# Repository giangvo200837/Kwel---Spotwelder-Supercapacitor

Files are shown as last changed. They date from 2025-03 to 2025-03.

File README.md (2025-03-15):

# PIC Microcontroller Spotwelder SuperCAP
 
# Supercapacitor Spot Welder – DIY & Fully Adjustable

This spot welder is a small project designed for use with two or three pairs of Nippon Chemi-Con 1400F 2.5V capacitors connected in series. The circuit features a dual-pulse control system with adjustable timing and setting memory, ensuring precise and reliable welds.
# Key Features:
- Using PIC18 Microcontroller.
- Integrated LM2596 CC 2A Charger.
- Management VCap and Balancing Circuit with customizable discharge resistors and mosfet DPAK package.
- Input Voltage Range: DC 10V-15V (max).
- OLED Display (128x64) for monitoring and adjustments.
- Adjustable Pulse from 1ms to 30ms and Pulse 2 upto 50ms.
- Using 10 MOSFETs AUIRF8409, IRL40SC228 or any D2PAK-7Pin.
- Using Mosfet Driver MIC4424 non-inverting with 3A/Port/5MOS total 6A for all Mosfet, reduce rise time and fall time for reduce power loss and dissipation, with 10 IRL40SC228, total time charge is ~400nS.
- Using max 2.5V per Cap or 5V series.
# Two Operation Mode:
- Auto Mode (duration by +0.5s per set).
- Manual Mode (controlled via foot pedal or switch).

   Everything is done by hand (DIY) without having to spend any processing steps, easy to do at home.
# Youtube Overview

IMAGE ALT TEXT HERE (https://www.youtube.com/watch?v=iMLx_PU4esA)
   
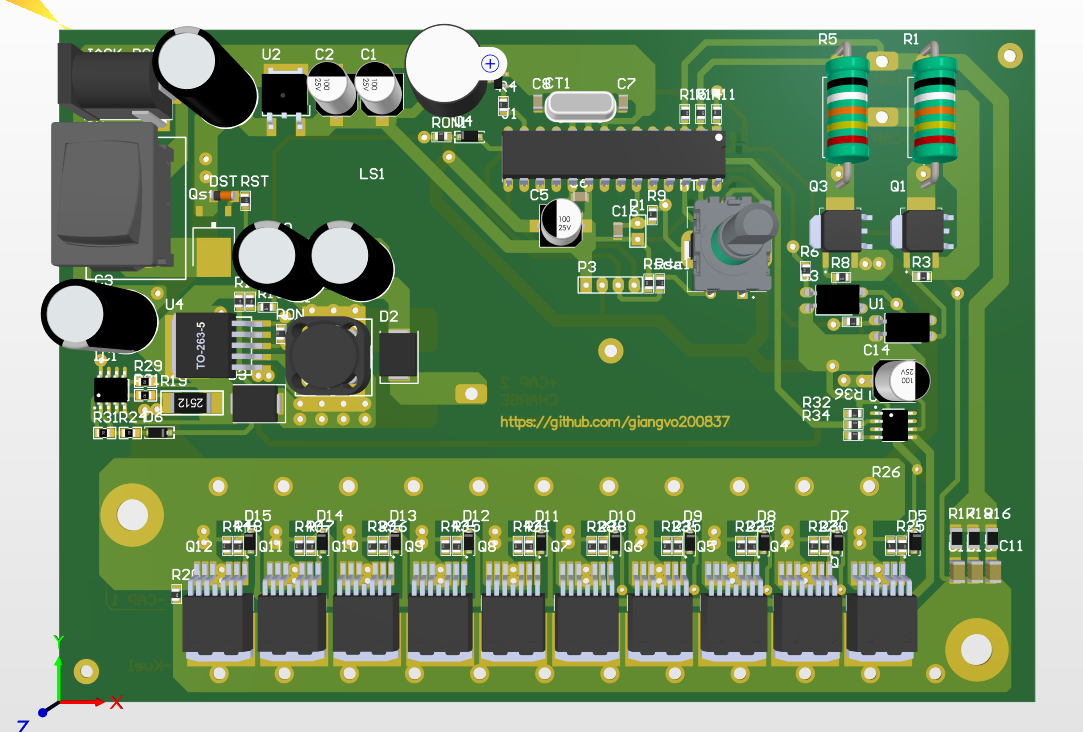
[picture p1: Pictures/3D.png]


I didn't add vias at the main power line and moved the part name on the top overlay because that's not necessary when diy PCB.

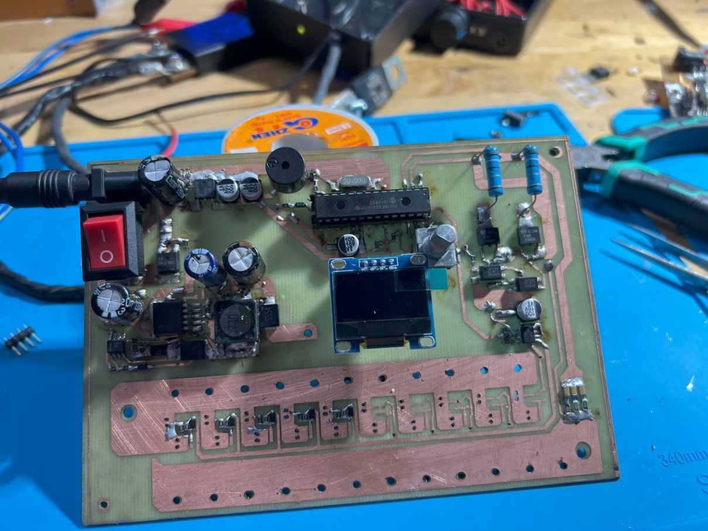
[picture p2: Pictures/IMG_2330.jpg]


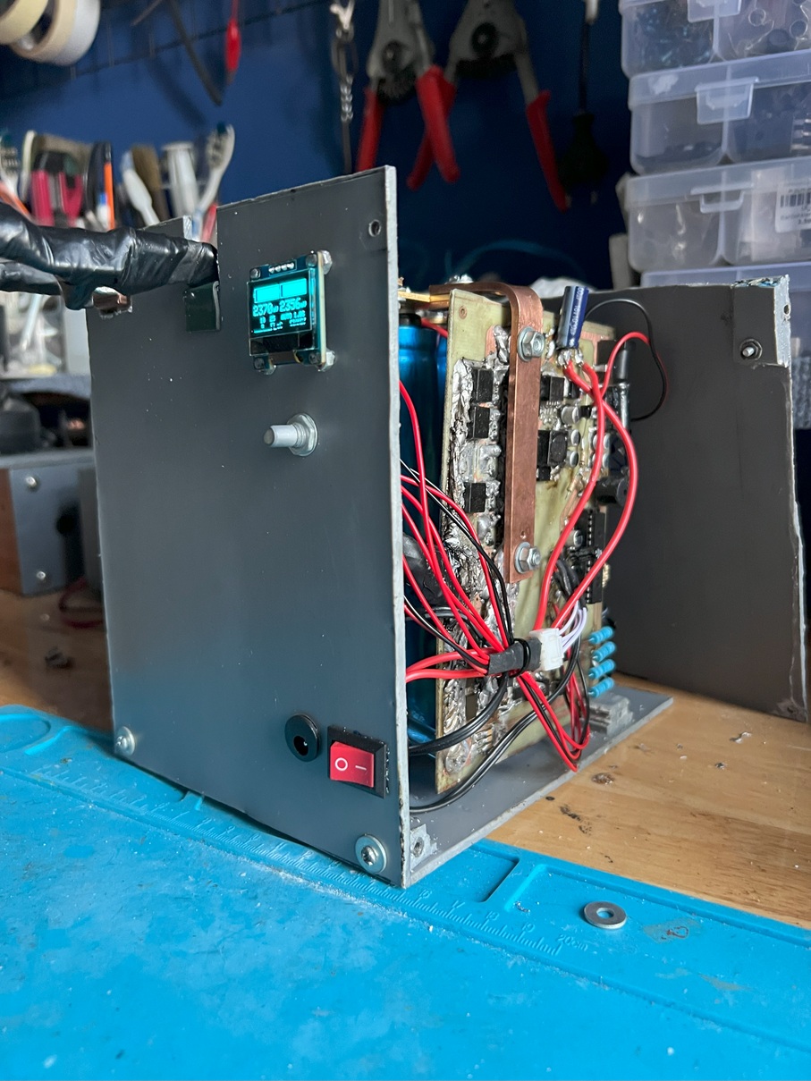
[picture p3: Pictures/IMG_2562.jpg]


# Connection Diagram

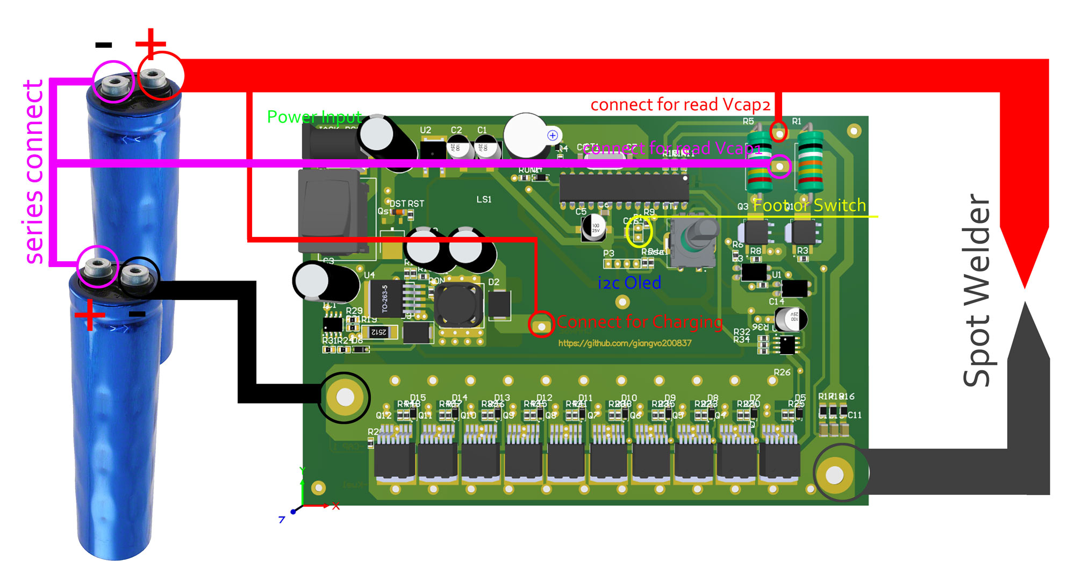
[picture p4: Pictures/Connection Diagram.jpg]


# Special Thanks
Simple Circuit SSD1306 Libraly custom for CCS C Compiler.

https://simple-circuit.com/ssd1306-oled-ccs-c-library/

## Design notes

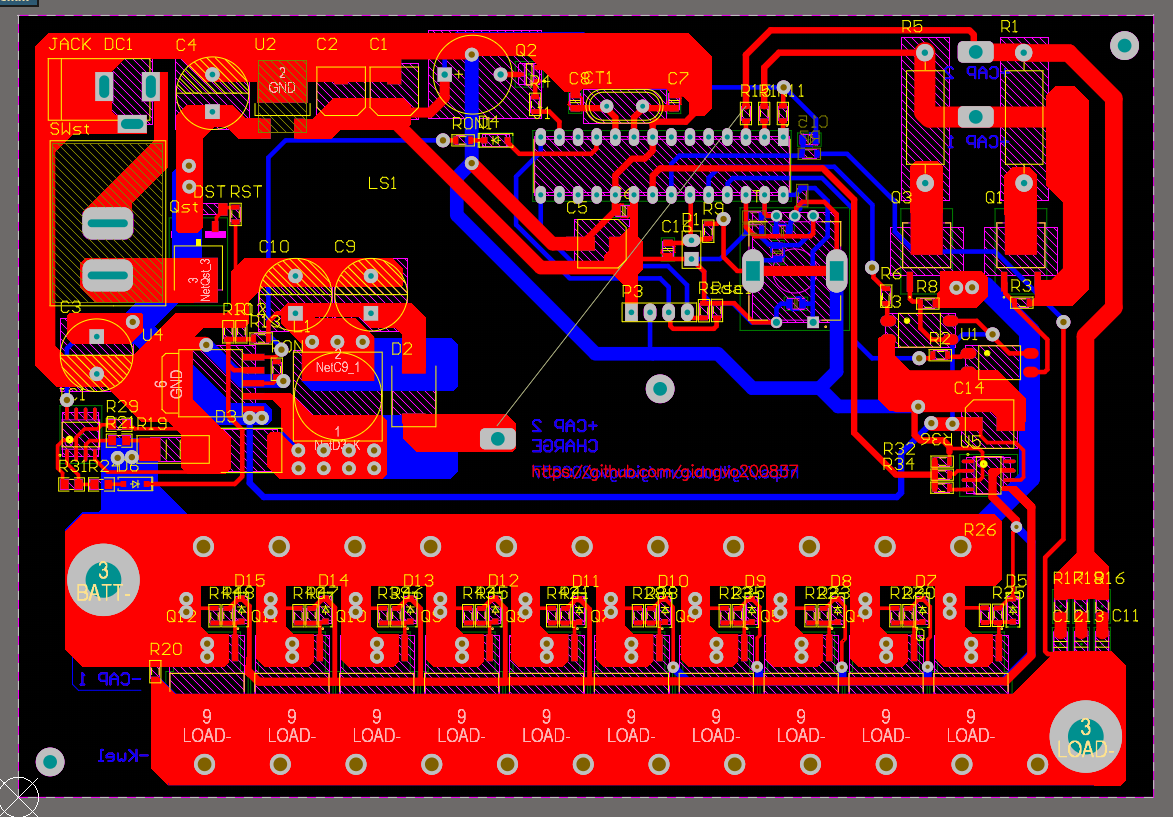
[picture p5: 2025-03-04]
Pictures/Layout.png

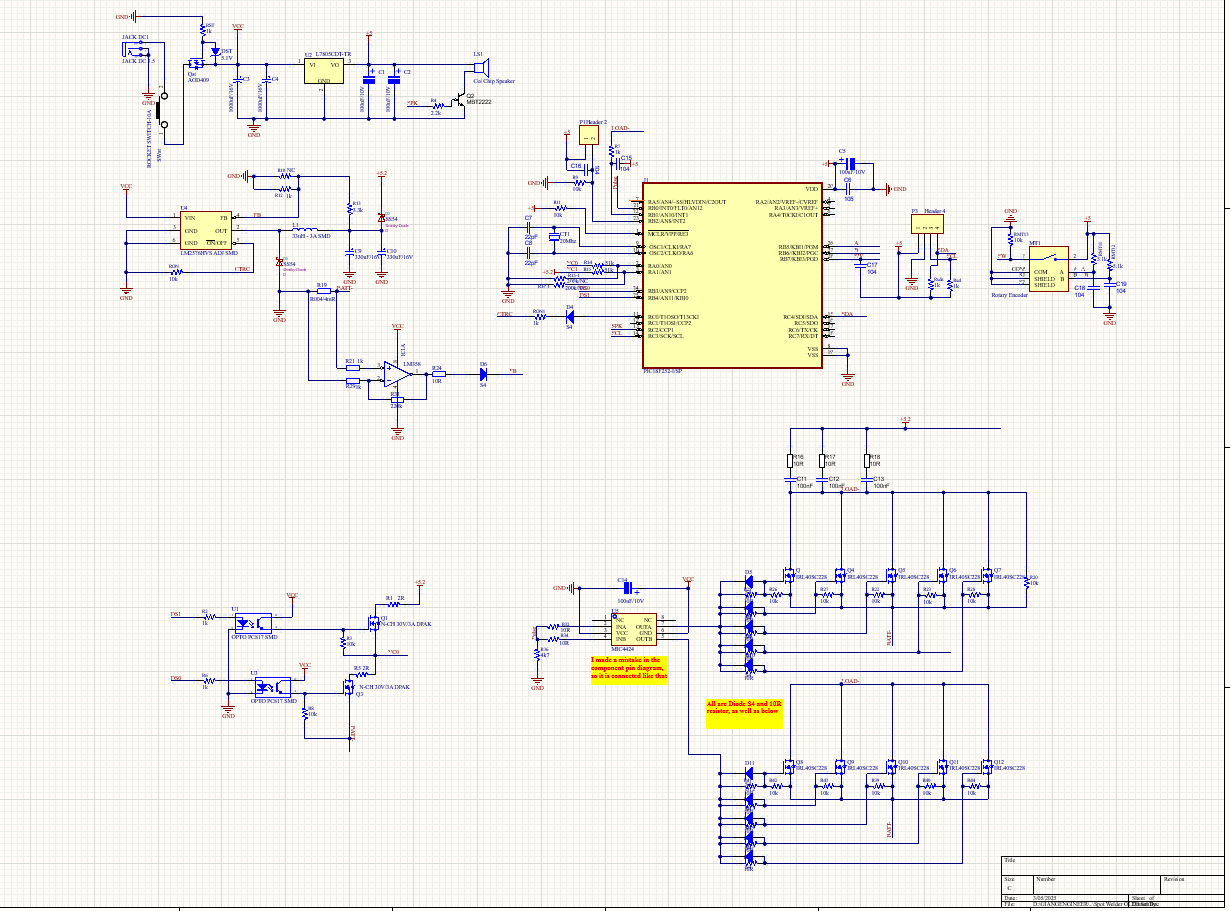
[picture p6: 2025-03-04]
Pictures/SCH.png

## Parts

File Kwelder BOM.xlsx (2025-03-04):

Comment | Description | Designator | Footprint | LibRef | Quantity
100uF/10V | Dán | C1, C2, C5, C14 | tu nhom 6.3 (d) | Tu Nhom 100uF 16V | 4
1000uF/16V | Cắm | C3, C4 | tu hoa 10mm | Tu Hoa 2200uF 16V 10x20 | 2
0805 | Capacitor SMD Cer 1.8nF 10% 50V X7R 0805 | C6, C7, C8, C15, C16, C17, C18, C19 | CAPC2012X135N | CAP C_0805 | 8
330uF/16V | Cắm | C9, C10 | tu hoa 10mm | Tu Hoa 2200uF 16V 10x20 | 2
1206 | Capacitor SMD Cer 220nF 10% 16V X7R 1206 | C11, C12, C13 | CAPC3216X180N | CAP C_1206 | 3
20Mhz | Crystal For all Crystal 2pin. | CT1 | CRYSTAL | CRYSTAL | 1
SS54 | SS54, [NoValue] | D2, D3 | DO-214AB_SMC | Schottky-Diode | 2
S4 | Dán | D4, D5, D6, D7, D8, D9, D10, D11, D12, D13, D14, D15 | DIODE SOD-123 | Diode S4 | 12
5.1V | Dán | DST | DIODE ZENNER SMD SOD80 | Diode Zener 5.1V | 1
LM358 | Low-Power Dual Operational Amplifier | IC1 | SOp 8 | LM358 | 1
PIC18F252-I/SP | PIC PICÂ® 18F Microcontroller IC 8-Bit 40MHz 32KB (16K x 16) FLASH 28-SPDIP | J1 | DIP787W46P254L3467H508Q28 | PIC18F252-I/SP | 1
JACK DC 5.5 | JACK DC 5.5 | JACK DC1 | JACK DC 5.5 | JACK DC 5.5 | 1
33uH - 3A SMD | Dán | L1 | Cuon Cam 12x12x10 | CUON CAM 100uH SMD | 1
Coi Chip Speaker | Còi chip | LS1 | Coi Chip Speacker | Coi Chip Speaker | 1
Rotary Encoder | Incremental Encoder, 12 Mm, Contact Rating 10 Ma - 5 Vdc | MT1 | XDCR_PEC11R-4215F-S0024 | PEC11R-4215F-S0024 | 1
Header 2 | Header, 2-Pin | P1 | HDR1X2 | Header 2 | 1
Header 4 | Header, 4-Pin | P3 | HDR1X4 | Header 4 | 1
N-CH 30V/3A DPAK | N-Channel 100 V 42A (Tc) 140W (Tc) Surface Mount D-Pak | Q1, Q3 | TO229P990X239-4N | IRFR3710ZTRPBF | 2
MBT2222 | Transistor SMD NPN 40V 600mA 250mW SOT23-3 | Q2 | SOT23-3 | NPN_MMBT2222A | 1
IRL40SC228 | OptiMOSâ„¢ 5 100V power MOSFET in TO-Leadless (TOLL) package with 60% space reduction for telecom and low voltage drives applications | Q, Q4, Q5, Q6, Q7, Q8, Q9, Q10, Q11, Q12 | DPAK127P1524X483-8N | IPT020N10N5 | 10
AOD409 | P-Channel 60V 26A (Tc) 2.5W (Ta), 60W (Tc) Surface Mount TO-252, (D-Pak) | Qst | TO252 | AOD409 | 1
2R | Res | R1, R5 | R2W | Res | 2
1k | Res | R2, R6, R7, R12, RON1, Rscl, Rsda, RST | SM-RES-0805 | Res SMD | 8
10k | Res | R3, R8, R9, R11, R20, R22, R23, R26, R27, R28, R39, R40, R42, R43, R44, RMT13, RON | SM-RES-0805 | Res SMD | 17
2.2k | Res | R4 | SM-RES-0805 | Res SMD | 1
NC | Res | R10 | SM-RES-0805 | Res SMD | 1
3.3k | Res | R13 | SM-RES-0805 | Res SMD | 1
200k/NC | Res | R14-1, R15-1 | SM-RES-0805 | Res SMD | 2
51k | Res | R14, R15 | SM-RES-0805 | Res SMD | 2
Thick Film | Resistor SMD chip 0.0 Ohm 0.25W 1206 | R16, R17, R18 | RESC3216N_ZERO | RES_1206 | 3
R004/4mR | Dán | R19 | tro smd 2512 | Tro 2512 5% 0.1R | 1
1k | Dán | R21, R29 | tro smd 0805 | Tro 0805 1% 1k | 2
10R | Dán | R24 | tro smd 0805 | Tro 0805 1% 1k | 1
10R | Res | R25, R30, R32, R33, R34, R35, R38, R41, R45, R46, R47, R48 | SM-RES-0805 | Res SMD | 12
220k | Dán | R31 | tro smd 0805 | Tro 0805 1% 33k | 1
4k7 | Res | R36 | SM-RES-0805 | Res SMD | 1
5.1k | Res | RMT11, RMT12 | SM-RES-0805 | Res SMD | 2
ROCKET SWITCH-10A | Rocker Switch SPDT 10A (AC) 125V Panel Mount, Snap-In | SWst | SW_2ARS_TH | SW1_10A-SRB23A2BBBNN-TH | 1
OPTO PC817 SMD | Single Opto | U1, U3 | SOP4 | OPTO PC817 SMD | 2
L7805CDT-TR | Linear Voltage Regulator IC 1 Output 1.5A DPAK | U2 | DPAK_118_446_112X59_SMD | REG_35V_5V-1.5A-7.5W-DPAK | 1
LM2576HVS ADJ SMD | Dán | U4 | TO263-5 | LM2576HVS ADJ SMD | 1
MIC4424 |  | U5 | SOp 8 | MIC4424 | 1

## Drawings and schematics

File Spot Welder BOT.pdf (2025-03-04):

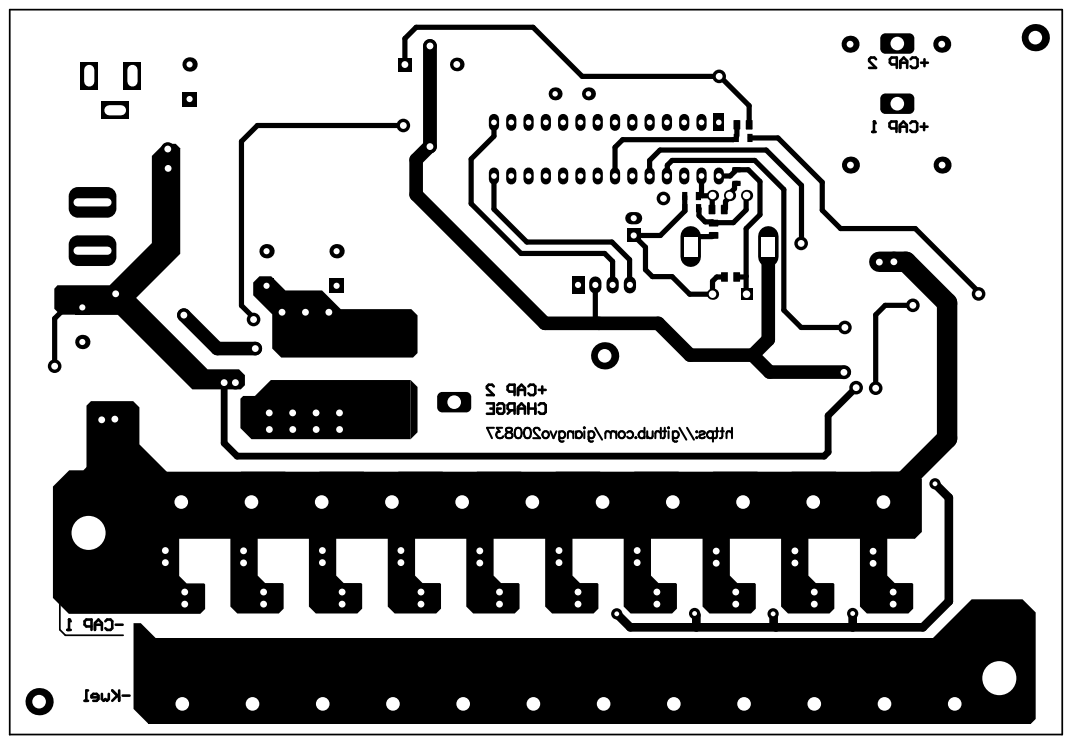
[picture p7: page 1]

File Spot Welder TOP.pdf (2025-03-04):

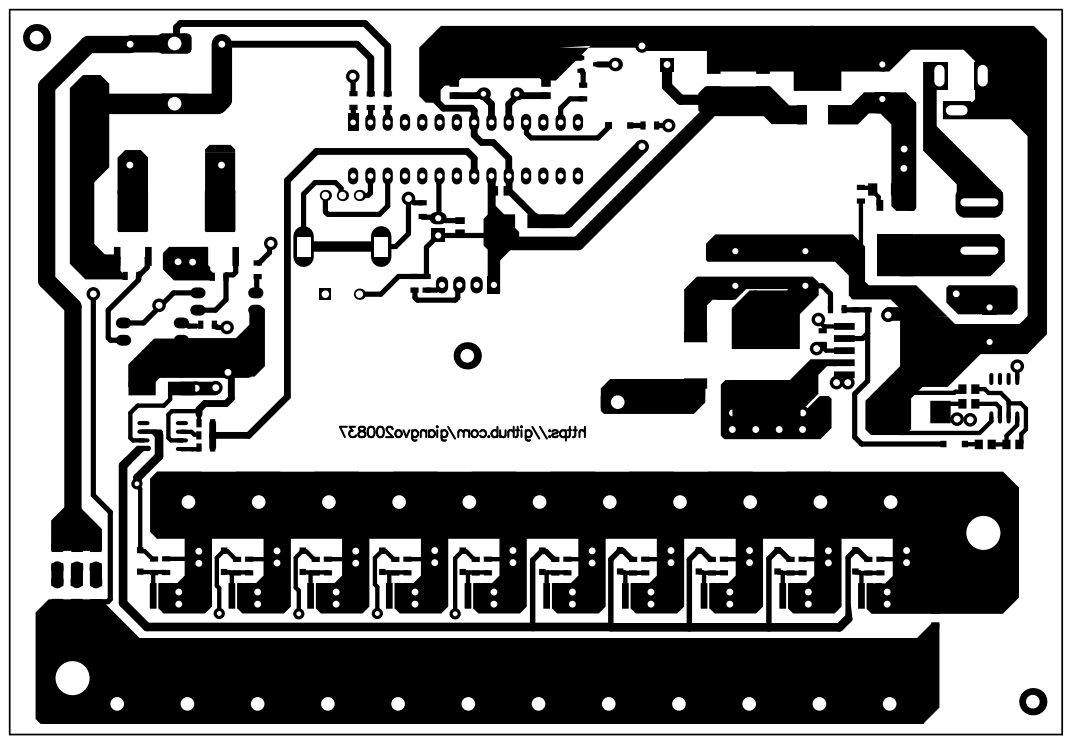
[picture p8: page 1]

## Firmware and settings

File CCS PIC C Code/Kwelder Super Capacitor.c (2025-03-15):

//#define SSD1306_RST    PIN_C0

#include <18F252.h>
#device ADC=10
#fuses HS, NOLVP, NOBROWNOUT, PUT, NOWDT, NOPROTECT
#use delay(clock=20MHz)
#use I2C(MASTER, I2C1, FAST = 400000, STREAM = SSD1306)
#define Charg PIN_C0
#define Pulse PIN_B0
#define button PIN_B7
#define sw_welder PIN_B2
#define welder_read PIN_B1
#define SPK PIN_C2
#define DS0 PIN_B3
#define DS1 PIN_B4
#define ENC_A PIN_B5  // Chân A cua encoder
#define ENC_B PIN_B6  // Chân B cua encoder
#define AN0_TO_AN1   0b0100
#include <SSD1306.c>      // include SSD1306 driver source code
#include <GFX_Library.c>  // include graphics library source code
#DEFINE LUUTRUT1 5
#DEFINE LUUTRUT2 10
#DEFINE LUUTRUC1 15
#DEFINE LUUTRUD1 20
// define random max number
#define RAND_MAX  (display_width - 1)
// include std library source code (required by rand() function)
#include <stdlib.h>
//!void testdrawrect(void) {
//!  for (int16_t i=0; i<display_height/2; i+=2) {
//!    display_drawRect(i, i, display_width-2*i, display_height-2*i, WHITE);
//!    display();
//!    delay_ms(1);
//!  }
//!}
int1 start = 0, dem_1 = 0,chedo = 0;
unsigned int8 chrgt = 0, chon = 0, dem = 0, dem_sw = 0, set_delay = 2, i = 0, a = 0;
//unsigned int percent0=0,bef0=64,percent1=0,bef1=0;
//unsigned int16 vt=0;
unsigned int16 Vcell[2];
unsigned int8 checkblc = 240, time1 = 1, time2 = 2;
unsigned int8 percent[2] = {0,0};
unsigned int8 before[2] = {128,64};
unsigned int16 dem2 = 65500, vcellr = 0;
int1 lastState = 0;
int1 currentState;
float Vtt = 0, seconds;
void drawrect(void)
{
   
   display_drawRect(7, 1, 58, 20,WHITE);
   display_drawRect(5, 8, 3, 5,WHITE);
   display_drawRect(70, 1, 58, 20,WHITE);
   display_drawRect(68, 8, 3, 5,WHITE);  
}

void balancing()
{

      if(Vcell[0] > 2499) {chrgt = 1;}
      if(chrgt == 1)      
         {
            output_high(Charg);
            output_high(DS0);
            output_low(DS1);
           // delay_ms(500); 
            
            if(Vcell[0] < Vcell[1])
            {
            output_low(Charg);
            output_low(DS0);
           // output_low(DS1); 
           chrgt = 0;
            }
          }
      if((Vcell[1] > 2499) && (chrgt == 0 )) {chrgt = 2;}
      if(chrgt == 2)
      {
         output_high(Charg);
         output_high(DS1);
         output_low(DS0);
         delay_ms(500); 
         chrgt = 2;
         if(Vcell[1] < Vcell[0])
         {
         output_low(Charg);
         output_low(DS0);
         output_low(DS1); 
         chrgt = 0;
         }
       }
       checkblc = 0;
   //}

    
}


int8 read_rotary(int8 counter)
{
        currentState = input(ENC_A);
        if (currentState != lastState) { // Kiem tra thay doi trang thái
            if (currentState == 0) { // Kiem tra huong quay
                if (input(ENC_B) == 0) {
                    counter++; 
                } else if(chon != 3) {
                    counter--; if(counter <= 1) {counter = 1;}
                }
            }
           if(dem2 >= 5000)
           {
            if(chon == 1) 
            {             
            if(counter >= 30) counter = 30;
            display_FillRect(17,45,12,8,black);
            display();
            display_setCursor(17, 45);
            printf(display_print,"%02u",counter);           
            display();
            //delay_ms(1);
            }
            
            if(chon == 2) 
            {
            
            if(counter >= 50) counter = 50;
            display_FillRect(42,45,12,8,black); 
            display();
            display_setCursor(42, 45);
            printf(display_print,"%02u",counter);
            display();
            //delay_ms(1);
            }
            
            if(chon == 3)
            {
            
            if(counter > 1) counter = 0;
            display_FillRect(58,45,66,8,black);
            display();
            display_setCursor(70, 45);
            if(counter == 1)
            {           
            display_print("AUTO");                      
            }
            else display_print("MANUAL"); 
            display();
            }
            
            if(chon == 4)
            {
            if(counter >= 6) counter = 6;
            display_FillRect(100,45,24,8,black); 
            display();
            display_setCursor(100, 45);
            seconds = counter;
            printf(display_print,"%1.1fS",seconds*0.5);
            display();
            }
            dem2 = 0;
           }
        }       
        lastState = currentState;
        return counter;
}

void read_analog(int adc_r)
   {    
   set_adc_channel(adc_r); 
   delay_ms(1);
   vcellr = 0;
   for (int z = 0; z<20; z++)
   {  
   vcellr = vcellr + read_adc();
   delay_us(100);
   }
   vcellr /= 20;
   Vcell[adc_r] = (float)(vcellr  * 5.0) / 1.023;  
   if(adc_r == 1) Vtt = Vcell[adc_r];
  // Vcell[adc_r] = 1450; // test voltage
   //return;
   }
   
void percentages(int16 volt)
 {
 if(volt>=2499) volt = 2499;
 percent[a] = (-0.022*(float)volt) + (128/(a+1)-1);
 if(percent[a] < before[a])  
 { 
    
   for(i = 128/(a+1); i > percent[a]; i--)
   {
   display_drawLine(i,3,i,18,WHITE); 
  if(start == 0) {display();} //first fill when start
   }  
 }
 
  if(percent[a] > before[a])  
 {  
   for(i = before[a]; i < percent[a]; i++)
   {
   display_drawLine(i,2,i,19,BLACK);  
  // display();
   }
 }
 before[a]=percent[a];
 //volt1=100;
 }

   
void draw_monitor(void)
{   
   display_FillRect(0,26,127,64,black);
   display_setTextColor(WHITE);
   display_setTextSize(1);   
   display_setCursor(50, 32);
   display_print("mV         mV");
   display_setCursor(17, 45);
   printf(display_print,"%02u",time1);
   display_setCursor(42, 45);
   printf(display_print,"%02u",time2);
   display_setCursor(59, 56);
   display_print("mS"); 
   display_setCursor(70, 45);
   if(chedo == 0)  display_print("MANUAL");
   else {
   display_print("AUTO");
   seconds = set_delay;
   display_setCursor(100, 45);
   printf(display_print,"%1.1fS",seconds*0.5);
   }
   display_setCursor(76, 55);
   printf(display_print,"Vp:%1.2fV",Vtt/1000); 
     //draw pulses    
   display_drawLine(1,63,20,63,WHITE);
   display_drawLine(20,63,20,55,WHITE);
   display_drawLine(20,55,23,55,WHITE);
   display_drawLine(23,55,23,63,WHITE);
   display_drawLine(23,63,43,63,WHITE);
   display_drawLine(43,63,43,55,WHITE);
   display_drawLine(43,55,50,55,WHITE);
   display_drawLine(50,63,50,55,WHITE);  
   display_drawLine(50,63,55,63,WHITE); 
   
   for(a = 0;a<2;a++)
      {  
         output_low(DS0);
         output_low(DS1);         
         read_analog(a); 
         if(chrgt == 1) output_high(DS0);        
         if(chrgt == 2) output_high(DS1); 
         Vcell[1] -= Vcell[0];         

         percentages(Vcell[a]);
         
         display_setTextSize(2);

         if(a == 1) display_setCursor(1, 26);
         if(a == 0) display_setCursor(68, 26); 
         printf(display_print,"%04lu",Vcell[a]);
         
//!         if((Vcell[0] == 0) && (Vcell[1] == 0)) 
//!         {
//!         
//!         display_FillRect(1,26,127,42,black);
//!         display_setCursor(19, 26);
//!         display_print("---  ---");
//!         }         
      }
      display();
      if((Vcell[0] > 2550) || (Vcell[1] > 2550))
      {
      Vcell[0] = Vcell[1] = 0; //drawrect();
      }     
      start = 1;     

}
void spotwelder_setup(void)
{        
         
         if(input(button)){
           while(input(button)){}//restart_wdt();delay_ms(200);}
           chon+=1;dem_1=1;
           if(chedo == 0) {if(chon > 3) chon = 5;}
           output_high(SPK);delay_ms(100);
           output_low(SPK);          
           if(chon <= 4)
           {
           display_FillRect(5,45,12,8,black); 
           display_FillRect(30,45,12,8,black); 
           display_FillRect(58,45,12,8,black);
           if(chedo == 1) {display_setCursor(100, 45);printf(display_print,"%1.1fS",seconds*0.5);}
           display();
           delay_ms(300);//restart_wdt();
           }          
           
           if (chon > 4) 
           {
           if(time1 >= 30) time1 = 30;
           if(time2 >= 50) time2 = 50;           
           write_eeprom(LUUTRUT1,time1);
           write_eeprom(LUUTRUT2,time2);
           write_eeprom(LUUTRUC1,chedo);
           write_eeprom(LUUTRUD1,set_delay);
           display_FillRect(0,26,127,64,WHITE);
           display_setTextColor(BLACK);
           display_setTextSize(2); 
           display_setCursor(40, 40);
           display_print("SAVED");
           display();delay_ms(1000);//restart_wdt();
           output_low(Charg);
           chon = 0; dem = 0; dem2 = 65500; break;  
          // reset_cpu();
           //break;//break;
            //break;
           }
         }
    if(chon == 1) { 
      time1 = read_rotary(time1);
    //  display_setTextSize(1);
    if(dem_1 == 1)
    {
      display_setCursor(5, 45);
      display_print(">>"); 
      display();
      dem_1 = 0;
    }
//!      display_setCursor(5, 45);
//!      display_print("  "); 
//!      display();
     // delay_ms(300);
    }
    if(chon == 2) {   
      time2 = read_rotary(time2); 
      //display_setTextSize(1); 
      if(dem_1 == 1)
    {
      display_setCursor(30, 45);
      display_print(">>"); 
      display();  
      dem_1 = 0;
    }
//!      display_setCursor(30, 45);
//!      display_print("  "); 
//!      display();
      //delay_ms(300);
    }
    if(chon == 3) { 
     // read_rotary();   
     chedo = read_rotary(chedo); 
      //display_setTextSize(1); 
      if(dem_1 == 1)
      {
      display_setCursor(58, 45);
      display_print(">>"); 
      display();
      dem_1 = 0;
      }
    }
    if(chon == 4) { 
     // read_rotary();   
     set_delay = read_rotary(set_delay); 
      //display_setTextSize(1); 
      if(dem_1 == 1)
      {
      display_setCursor(93, 45);
      display_print(">"); 
      display();
      dem_1 = 0;
      }
//!      display_setCursor(68, 45);
//!      display_print("  "); 
//!      display();
     // delay_ms(300);
    }
   // restart_wdt();
    dem2+=1;//if(dem2 > 5000) dem2 = 5000;
    //delay_us(10);
}

void spotwelder_start(int8 pulse1, pulse2)
   {  
      //setup_wdt(WDT_ON);
      //pulse_interval = pules1; if(pulse_interval >= 10) pulse_interval = 10;
      output_high(SPK);
      output_high(Pulse);delay_ms(pulse1);
      if(pulse1 > 10) pulse1 = 10;         //interval  
      output_low(Pulse);delay_ms(pulse1); //interval
      //restart_wdt(); 
      output_high(Pulse);delay_ms(pulse2);
      output_low(Pulse);delay_ms(10);
      //restart_wdt(); 
      output_low(SPK); //delay_ms(100);
//!      for(int z = 0; z < 5; z++)
//!      {
//!      delay_ms(100); 
//!      restart_wdt(); 
//!      }
      output_low(Pulse); //for sure
     // break;
     // restart_wdt(); 
     // setup_wdt(WDT_OFF);
   }


void main(void)
{
  // by default, we'll generate the high voltage from the 3.3v line internally! (neat!)
  // initialize with the I2C addr 0x7A (for the 128x64)
  // SSD1306 OLED display I2C address may be 0x7A or 0x78
 
  SET_TRIS_A(0B00000011);
  SET_TRIS_B(0b11100110);
  SET_TRIS_C(0b11000);
  output_low(Pulse);
  output_low(Charg);
  output_low(SPK);
  output_low(DS0);
  output_low(DS1);
  lastState = input(ENC_A);
//!  output_low(Pulseex);
//!  for(int h = 0; h<5; h++)
//!  {
//!  output_high(Pulseex);delay_ms(1000);
//!  output_low(Pulseex);delay_ms(1000);
//!  }
  setup_adc(ADC_CLOCK_DIV_8); 
  SETUP_ADC_PORTS(AN0_TO_AN1);
 // setup_wdt(WDT_2304MS);
  // setup_wdt(WDT_OFF);
 // restart_wdt();
  //setup_wdt(WDT_288MS);
 // SSD1306_begin(SSD1306_SWITCHCAPVCC, 0x7A); // test code
  SSD1306_begin(SSD1306_SWITCHCAPVCC, 0x78); // load code
  
  time1 = read_eeprom(LUUTRUT1); if(time1 >  99) {time1 = 3; write_eeprom(LUUTRUT1,time1);}
  time2 = read_eeprom(LUUTRUT2); if(time2 >  99) {time2 = 5;write_eeprom(LUUTRUT2,time2);} 
  chedo = read_eeprom(LUUTRUC1); if(chedo >  1) {chedo = 0;write_eeprom(LUUTRUC1,chedo);}
  set_delay = read_eeprom(LUUTRUD1); if(set_delay >  6) {set_delay = 2;write_eeprom(LUUTRUD1,set_delay);}
   //display_clear();
//!   display();
//!   delay_ms(1000);
   ssd1306_command(SSD1306_SETCONTRAST);
   ssd1306_command(0xB9);
//!   display_FillRect(0,0,127,63,white);
//!   display_setTextColor(Black);
//!   display_setTextSize(3); 
//!   display_setCursor(2, 25);
//!   display_print("GIANG J");
   //display_FillRect(0,0,127,63,black);
   display();
  // restart_wdt();
   output_high(SPK); delay_ms(500);
   output_low(SPK);
   delay_ms(2000);
   //restart_wdt();
   display_clear();
   drawrect();
  //output_high(Charg);
  // init done
  while(true)
  {  

  if(dem2 >= 65500)
  {
    draw_monitor();
    //display();
    checkblc+=1; if (checkblc > 10) {checkblc = 10;}
     dem2=0;
  }
  

  
if((Vcell[0] > 1000) && (Vcell[1] > 1000) && (time1 <= 30) && (time2 <= 50))
{
 if(dem == 0)
   { 
   //do spotwelder
   if(chedo == 0)
   {
      if(input(sw_welder)){ 
      while(true){spotwelder_start(time1, time2);dem2=65500;break;}
      delay_ms(500);
      }
      else {}
   }
   if(chedo == 1)
   {        
      if(input(welder_read)) {while(input(welder_read)){delay_ms(100);dem_sw+=1;if(dem_sw >= set_delay*5){break;}}}//restart_wdt();delay_ms(1000);restart_wdt();delay_ms(1000);restart_wdt();}   
      if(dem_sw < set_delay*5) {dem_sw = 0;}
      if(dem_sw >= set_delay*5)
      {
      if(input(welder_read)) {           
      while(true){spotwelder_start(time1, time2);dem2=65500;break;}      
      }
     // else dem_sw= 0; break;
      }      
   }
   }
   //restart_wdt();
}

if(checkblc >= 10) {balancing();}

 while(dem != 0)
   {
   // do setup spotwelder
   //draw_monitor();
   //display();
    chrgt = 0;
    output_high(Charg);
    output_low(DS0);
    output_low(DS1); 
    output_low(Pulse); 
   display_setTextSize(1);
   spotwelder_setup();
  // restart_wdt();
   }
  
     if(input(button))
      { 
         delay_ms(500);//restart_wdt();
       //  if(input(button)) chon =  dem = 1;      
         if(input(button)){
         dem_1 = chon =  dem = 1;
         //chrgt = 0;
         //output_low(Pulse);
        // output_highCharg);
         output_high(SPK);
         delay_ms(100);
         output_low(SPK);
         }
         while(input(button)){delay_ms(100);}//restart_wdt();
         //restart_wdt();
        // else dem = 0;
         //delay_ms(500);
         //if(input(button)) dem = 1;
         //SSD1306_ClearDisplay();
      }
      

  //dem+=1; delay_ms(100);
dem_sw = 0;
dem2++;//restart_wdt();
}
}

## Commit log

2025-03-04 Create Kwelder BOM.xlsx
    [Kwelder BOM.xlsx]
2025-03-04 Update Kwelder Super Capacitor.c
2025-03-05 fix pcb
    [PCB_Project.PrjPcb, Spot Welder Layout.PcbDoc, Spot Welder OLED.SchDoc]
2025-03-15 update Vpack monitor, fix:some errors time se t- display fill battery.
    [Kwelder Super Capacitor.c]
